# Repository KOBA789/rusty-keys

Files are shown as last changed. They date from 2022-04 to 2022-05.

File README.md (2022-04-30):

# RustyKeys

RustyKeys は、組込み Rust 入門に最適な1台を目指して開発された自作キーボードのキットです。

## このリポジトリの内容

このリポジトリは rusty-keys のファームウェアのサンプルコードと、基板の設計データを含んでいます。

- [`firmware`](./firmware): ファームウェアのサンプルコード
- [`pcb`](./pcb): 基板の設計データ

## ビルドガイド

RustyKeys の詳しい仕様や組み立て方についてはビルドガイドをご覧ください。

[RustyKeys ビルドガイド](https://rusty-keys.koba789.com/)

## 入手方法

RustyKeys キットは遊舎工房さんから購入できます。詳しい入手方法は以下のページをご覧ください。

[RustyKeys キットを入手する](https://rusty-keys.koba789.com/get_rusty_keys)

## 質問などは Discussions へ！

組み立てやファームウェア開発に関する質問は GitHub Discussions で受け付けています。
すべての質問にお答えすることを保証するものではありませんが、できる限りサポートしますので困ったときには思い出してみてください。

[RustyKeys Discussions](https://github.com/KOBA789/rusty-keys/discussions)

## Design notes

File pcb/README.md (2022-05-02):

# 基板の設計データ
KiCad 6.0.4 を用いて設計しています。

## 販売されているモデルとの違い
裏面のロゴデータが含まれていないことが唯一の違いです。

※表面の "RustyKeys" ロゴは含まれています。

## パーツリスト(BOM)
調達元は参考情報です。同型・互換の製品であれば他のパーツを使ってもよいでしょう。

- Raspberry Pi Pico x2　(調達元: [遊舎工房](https://shop.yushakobo.jp/products/raspberry-pi-pico), [秋月電子通商](https://akizukidenshi.com/catalog/g/gM-16132/))
- 1N4148 x6 (調達元: [遊舎工房](https://shop.yushakobo.jp/products/a0800di-01-100), [秋月電子通商](https://akizukidenshi.com/catalog/g/gI-16603/))
- L字ピンヘッダ(3P) x1 (調達元: [秋月電子通商](https://akizukidenshi.com/catalog/g/gC-15510/))
- ジャンパ線(ソケット-ソケット 3P) x1 (調達元: [秋月電子通商](https://akizukidenshi.com/catalog/g/gC-15384/))
- ピンヘッダ(40P) x1 (調達元: [秋月電子通商](https://akizukidenshi.com/catalog/g/gC-00167/))
  - 20P x1 でも代用できます (調達元: [秋月電子通商](https://akizukidenshi.com/catalog/g/gC-16590/))
- ゴム足 x4 (調達元: [Amazon.co.jp](https://www.amazon.co.jp/dp/B07QKFW6F6))
  - 直径 5mm x 高さ 2mm 程度のものなら代用できます
  - TRUSCO の TP6R-90 もおすすめです (調達元: [Amazon.co.jp](https://www.amazon.co.jp/dp/B01B4CQVFK))

## 利用しているシンボル・フットプリントライブラリ

- [Keyswitch Kicad Library](https://github.com/perigoso/keyswitch-kicad-library)
- [KiCad-RP-Pico](https://github.com/ncarandini/KiCad-RP-Pico)

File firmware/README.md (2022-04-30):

# ファームウェアのサンプルコード

- [`hello`](./hello): デバッグ出力に `Hello, world!` を出力します
- [`keyboard`](./keyboard): USB キーボードのサンプルコードが何種類か入っています

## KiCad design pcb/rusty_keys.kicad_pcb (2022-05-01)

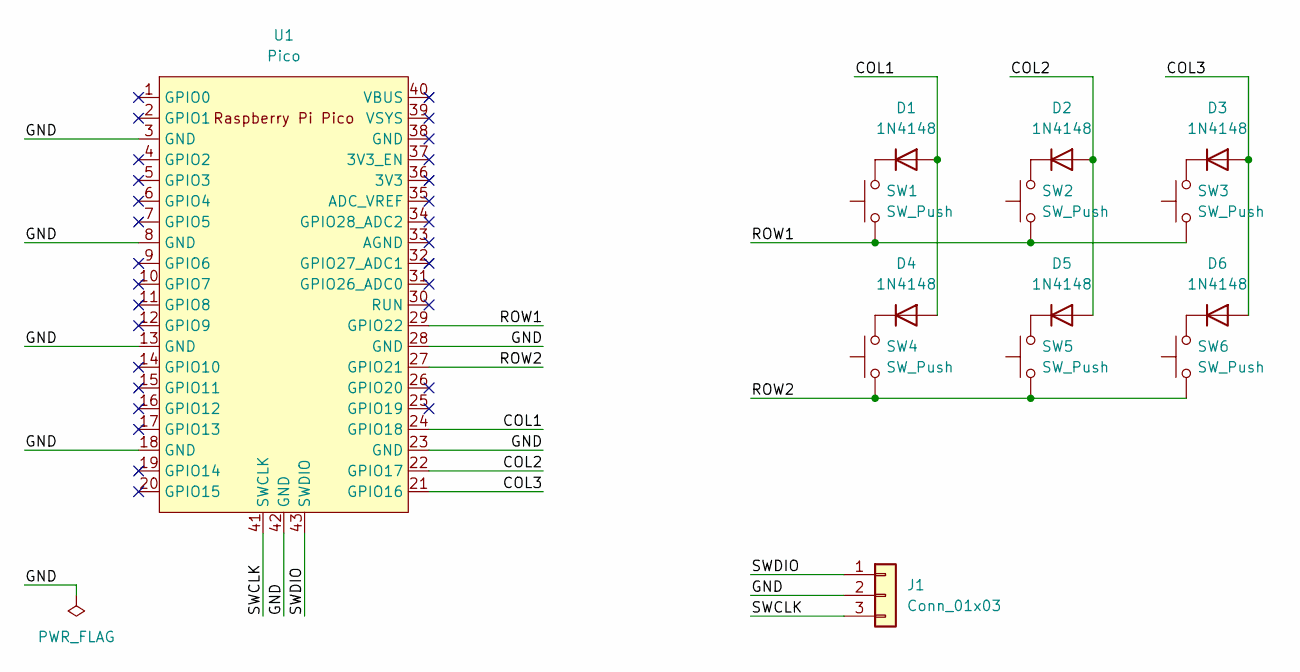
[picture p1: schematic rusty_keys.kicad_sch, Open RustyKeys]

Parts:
D1, D2, D3, D4, D5, D6: 1N4148; D_DO-35_SOD27_P7.62mm_Horizontal
J1: Conn_01x03; PinHeader_1x03_P2.54mm_Horizontal
SW1, SW2, SW3, SW4, SW5, SW6: SW_Push; SW_Cherry_MX_PCB_1.00u
U1: Pico; RPi_Pico_SMD_TH

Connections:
/COL1: D1.2 (A), D4.2 (A), U1.24 (GPIO18)
/COL2: D2.2 (A), D5.2 (A), U1.22 (GPIO17)
/COL3: D3.2 (A), D6.2 (A), U1.21 (GPIO16)
/GND: J1.2, U1.3 (GND), U1.8 (GND), U1.13 (GND), U1.18 (GND), U1.23 (GND), U1.28 (GND), U1.42 (GND)
/ROW1: SW1.1, SW2.1, SW3.1, U1.29 (GPIO22)
/ROW2: SW4.1, SW5.1, SW6.1, U1.27 (GPIO21)
/SWCLK: J1.3, U1.41 (SWCLK)
/SWDIO: J1.1, U1.43 (SWDIO)
unnamed: D1.1 (K), SW1.2
unnamed: D2.1 (K), SW2.2
unnamed: D3.1 (K), SW3.2
unnamed: D4.1 (K), SW4.2
unnamed: D5.1 (K), SW5.2
unnamed: D6.1 (K), SW6.2

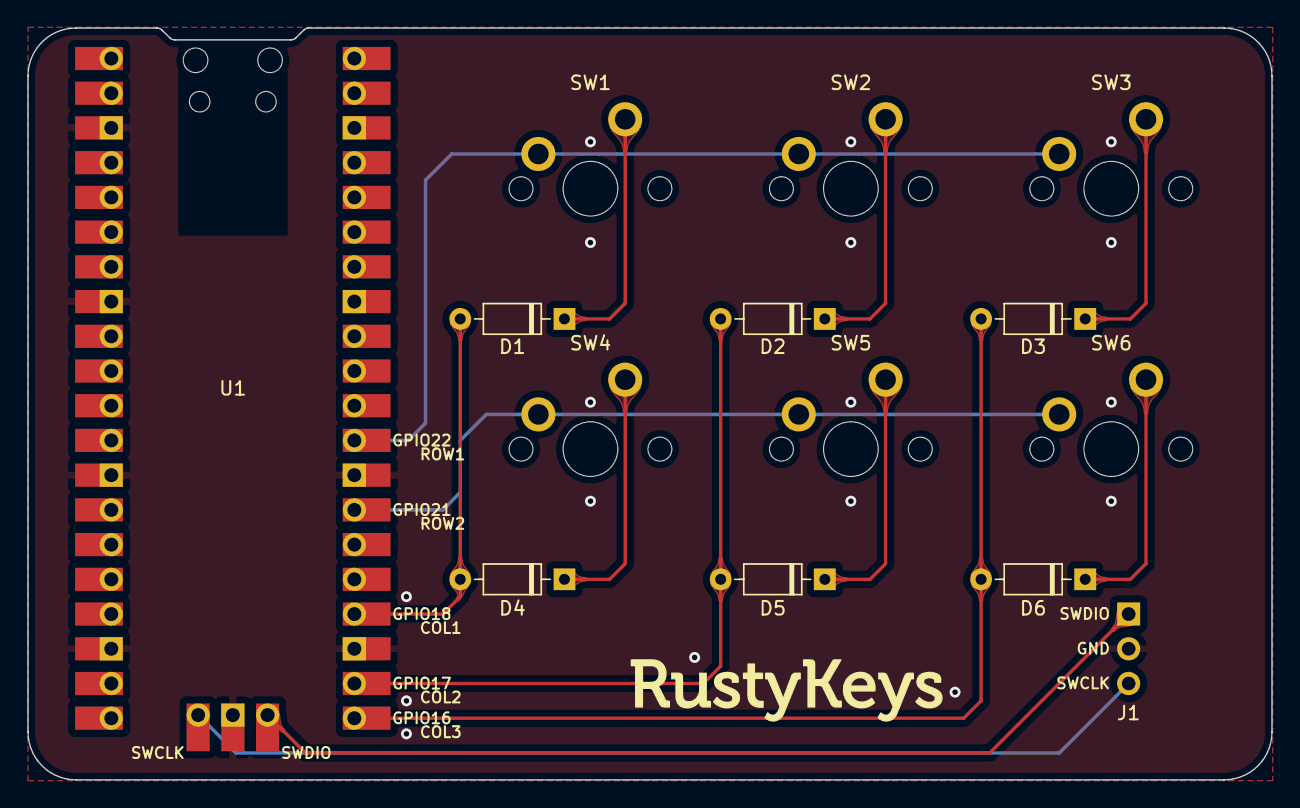
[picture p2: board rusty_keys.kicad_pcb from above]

Board: 2 copper layers, 91.0 x 55.0 mm, 14 parts (0 on the bottom side), 14 nets.

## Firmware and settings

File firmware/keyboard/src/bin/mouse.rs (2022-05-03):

#![no_main]
#![no_std]

use core::convert::Infallible;

use bsp::hal::{self, usb::UsbBus};
use cortex_m::{asm, prelude::*};
use cortex_m_rt::entry;
use defmt_rtt as _;
use embedded_hal::digital::v2::{InputPin, OutputPin};
use embedded_time::duration::Extensions as _;
use hal::pac;
use panic_probe as _;
use rp_pico as bsp;
use usb_device as usbd;
use usbd::{
    class_prelude::UsbBusAllocator,
    device::{UsbDeviceBuilder, UsbVidPid},
};

use usbd_hid::{
    descriptor::{MouseReport, SerializedDescriptor},
    hid_class::{
        HIDClass, HidClassSettings, HidCountryCode, HidProtocol, HidSubClass, ProtocolModeConfig,
    },
};

#[defmt::panic_handler]
fn panic() -> ! {
    cortex_m::asm::udf()
}

pub fn exit() -> ! {
    loop {
        cortex_m::asm::bkpt();
    }
}

#[entry]
fn main() -> ! {
    let mut p = pac::Peripherals::take().unwrap();
    let mut watchdog = hal::Watchdog::new(p.WATCHDOG);
    let clocks = hal::clocks::init_clocks_and_plls(
        bsp::XOSC_CRYSTAL_FREQ,
        p.XOSC,
        p.CLOCKS,
        p.PLL_SYS,
        p.PLL_USB,
        &mut p.RESETS,
        &mut watchdog,
    )
    .ok()
    .unwrap();
    let timer = hal::Timer::new(p.TIMER, &mut p.RESETS);

    let bus = UsbBus::new(
        p.USBCTRL_REGS,
        p.USBCTRL_DPRAM,
        clocks.usb_clock,
        true,
        &mut p.RESETS,
    );
    let bus_allocator = UsbBusAllocator::new(bus);
    let vid_pid = UsbVidPid(0x6666, 0x0789);
    let mut hid = HIDClass::new_with_settings(
        &bus_allocator,
        MouseReport::desc(),
        10,
        HidClassSettings {
            subclass: HidSubClass::NoSubClass,
            protocol: HidProtocol::Mouse,
            config: ProtocolModeConfig::ForceReport,
            locale: HidCountryCode::NotSupported,
        },
    );

    let mut dev = UsbDeviceBuilder::new(&bus_allocator, vid_pid)
        .manufacturer("KOBA789")
        .product("RustyKeys")
        .serial_number("789")
        .build();

    let sio = hal::Sio::new(p.SIO);
    let pins = bsp::Pins::new(p.IO_BANK0, p.PADS_BANK0, sio.gpio_bank0, &mut p.RESETS);

    let col1 = pins.gpio18.into_pull_up_input();
    let col2 = pins.gpio17.into_pull_up_input();
    let col3 = pins.gpio16.into_pull_up_input();
    let mut row1 = pins.gpio22.into_push_pull_output();
    let mut row2 = pins.gpio21.into_push_pull_output();
    let cols: &[Column] = &[&col1, &col2, &col3];
    let rows: &mut [Row] = &mut [&mut row1, &mut row2];

    let mut scan_countdown = timer.count_down();
    scan_countdown.start(10.milliseconds());

    loop {
        dev.poll(&mut [&mut hid]);

        if scan_countdown.wait().is_ok() {
            let state = scan_keys(rows, cols);
            let report = build_report(&state);
            hid.push_input(&report).ok();
        }
        // drop received data
        hid.pull_raw_output(&mut [0; 64]).ok();
    }
}

pub type Column<'a> = &'a dyn InputPin<Error = Infallible>;
pub type Row<'a> = &'a mut dyn OutputPin<Error = Infallible>;
pub type StateMatrix = [[bool; 3]; 2];

fn scan_keys(rows: &mut [Row], cols: &[Column]) -> StateMatrix {
    let mut matrix = [[false; 3]; 2];
    for (row_pin, row_state) in rows.iter_mut().zip(matrix.iter_mut()) {
        row_pin.set_low().unwrap();
        asm::delay(10);
        for (col_pin, col_state) in cols.iter().zip(row_state.iter_mut()) {
            *col_state = col_pin.is_low().unwrap();
        }
        row_pin.set_high().unwrap();
        asm::delay(10);
    }
    matrix
}

fn build_report(matrix: &StateMatrix) -> MouseReport {
    let mut buttons = 0;
    let mut x = 0;
    let mut y = 0;

    if matrix[1][0] {
        x -= 5;
    }
    if matrix[1][2] {
        x += 5;
    }
    if matrix[0][1] {
        y -= 5;
    }
    if matrix[1][1] {
        y += 5;
    }
    if matrix[0][0] {
        buttons += 0b1 << 0; // LEFT CLICK
    }
    if matrix[0][2] {
        buttons += 0b1 << 1; // RIGHT CLICK
    }

    MouseReport {
        buttons,
        x,
        y,
        wheel: 0,
        pan: 0,
    }
}

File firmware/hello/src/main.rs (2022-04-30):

#![no_main]
#![no_std]

use defmt_rtt as _;
use panic_probe as _;
use rp_pico as _;

#[defmt::panic_handler]
fn panic() -> ! {
    cortex_m::asm::udf()
}

pub fn exit() -> ! {
    loop {
        cortex_m::asm::bkpt();
    }
}

#[cortex_m_rt::entry]
fn main() -> ! {
    defmt::println!("Hello, world!");

    exit()
}

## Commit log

2022-05-01 Add KiCad project data
    [rusty_keys.kicad_pcb, rusty_keys.kicad_sch]
2022-05-01 Fix typo: "游" => "遊"
2022-05-03 Add mouse device example
